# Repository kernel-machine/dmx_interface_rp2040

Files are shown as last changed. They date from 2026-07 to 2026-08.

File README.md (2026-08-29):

<div align="center">

# 🎛️ DMX USB Interface — Dual Universe

### Enttec DMX USB Pro Mk2 Emulator · Built on Raspberry Pi Pico (RP2040)






<br>

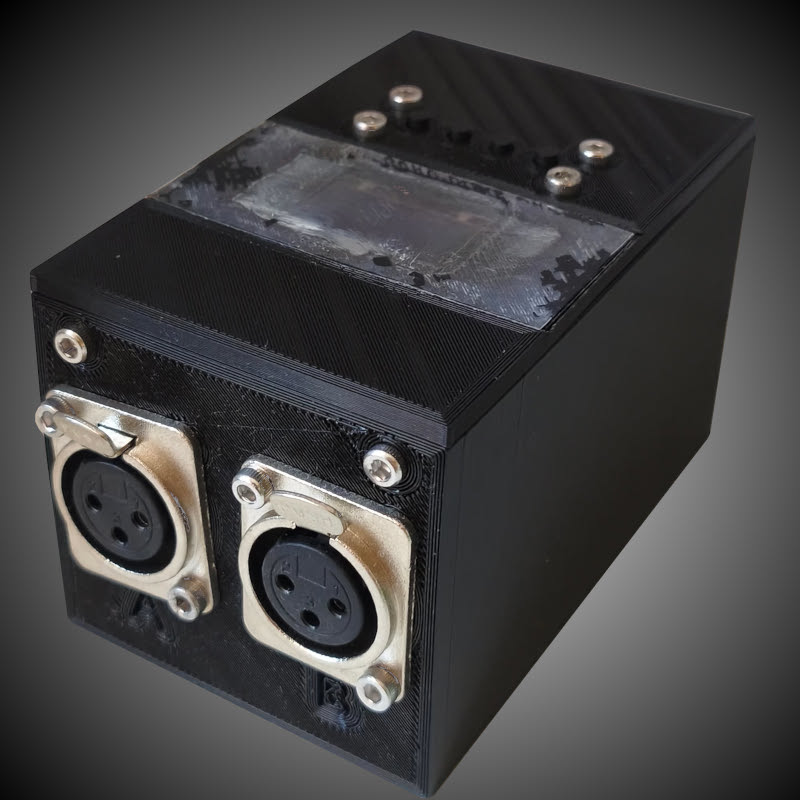
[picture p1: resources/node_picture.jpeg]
DMX USB Node


<br>

*A DIY, open-source, dual-universe DMX interface with an OLED menu, standalone CUE engine, and full galvanic isolation.*

</div>

---

## 💡 Motivation

Lighting control hardware is often expensive and hard to customize. This project provides an **affordable, reliable, and highly customizable** dual-universe DMX interface using the Raspberry Pi Pico.

By emulating the industry-standard **Enttec DMX USB Pro Mk2** protocol, the interface works **out of the box** with popular lighting software like [QLC+](https://www.qlcplus.org/) — no custom drivers required.

It also features a built-in **OLED display**, **physical controls**, and a **standalone CUE engine** for managing DMX setups directly from the device.

> **Why USB instead of ArtNet?**
> My first prototype used ArtNet, but for my use cases it was far more convenient to connect via USB rather than dealing with LAN cables, IP addresses, and DHCP configuration.

---

## 📺 Demo

Menu navigation and node introduction:

<div align="center">

Watch the demo on YouTube (https://youtu.be/CNQFU6lT2Z0)

*▶️ Click the image above to watch the video on YouTube*

</div>

---

## ✨ Features

| Feature | Description |
|---|---|
| 🔌 **Enttec Pro Mk2 Emulation** | Native compatibility with QLC+ and other major lighting software |
| 🎚️ **Dual Universe Output** | Two full DMX-512 universes via MAX485 transceivers |
| 🖥️ **OLED Menu System** | Integrated SSD1306 display + 4-button interface for on-device control |
| 💾 **Standalone CUE Engine** | Record and store up to 10 dual-universe CUEs to flash memory |
| 🔀 **DMX Crossfading** | Smooth transitions with configurable fade times |
| 🛣️ **Advanced Routing** | Flexible mapping of Universe 1/2 to physical Outputs A/B |
| 💿 **Persistent Settings** | All preferences saved to EEPROM |

### 🔌 Smart Disconnect Behavior

Configurable fallback modes when USB connection is lost:

- ⬛ **Blackout** — all channels go to zero
- ⏸️ **Hold Last Value** — freeze the last DMX frame
- 🎬 **Play CUE** — automatically trigger a stored CUE

---

## 🚀 How to Flash

This project uses **PlatformIO** with the Arduino framework for the Raspberry Pi Pico ([Earle Philhower core](https://github.com/earlephilhower/arduino-pico)).

### Option 1 — PlatformIO Upload *(Recommended)*

1. Install [Visual Studio Code](https://code.visualstudio.com/) and the [PlatformIO IDE extension](https://platformio.org/).
2. Open this project folder in VSCode.
3. Hold the **BOOTSEL** button on the Pico and plug it in via USB.
4. Once the Pico mounts as a mass storage device, click **Upload** (→) in the PlatformIO toolbar.

### Option 2 — Drag & Drop (UF2)

1. Build the project in PlatformIO (**Build** / ✓ icon).
2. Find the generated `firmware.uf2` in `.pio/build/pico/`.
3. Hold **BOOTSEL** and plug in the Pico — it appears as `RPI-RP2`.
4. Drag and drop `firmware.uf2` onto the drive. The Pico reboots automatically.

---

## 🧰 Hardware

The circuit implements **full galvanic isolation** between the USB controller and the DMX transceiver to protect the host computer from electrical faults, ground loops, and high-voltage transients.

An isolated DC-DC converter (**B0505S-1W**) supplies a dedicated floating 5 V rail, and two high-speed **6N137** optocouplers isolate the logic signals driving the MAX485.

### Bill of Materials

| # | Component | Link |
|:-:|---|---|
| 1 | **Raspberry Pi Pico (RP2040)** | [AliExpress](https://it.aliexpress.com/item/1005006087823796.html) |
| 2 | **MAX485 Transceiver Module** ×2 | [AliExpress](https://s.click.aliexpress.com/e/_c3NT3dPz) |
| 3 | **XLR 3-Pin Female Panel Connector** ×2 | [AliExpress](https://s.click.aliexpress.com/e/_c4q55Lx9) |
| 4 | **6N137 High-Speed Optocoupler** ×2 | [AliExpress](https://s.click.aliexpress.com/e/_c2JoN82B) |
| 5 | **B0505S-1W Isolated DC-DC Converter** | [AliExpress](https://s.click.aliexpress.com/e/_c4KkuvZv) |
| 6 | **Perfboard / PCB** | [AliExpress](https://it.aliexpress.com/item/1005006066751179.html) |
| 7 | **Tactile Push Buttons** ×4 | [AliExpress](https://it.aliexpress.com/item/1005005658595026.html) |
| 8 | **SSD1306 0.96″ OLED Display** | [AliExpress](https://s.click.aliexpress.com/e/_c4LZoMDz) |
| 9 | **Assorted Resistors** | — |
| 10 | **3D Printed Case** *(optional)* | See below |

---

### 📐 Wiring Diagram

> [!NOTE]
> This diagram was drawn after the build, so minor inaccuracies are possible — but it should be correct.

<div align="center">
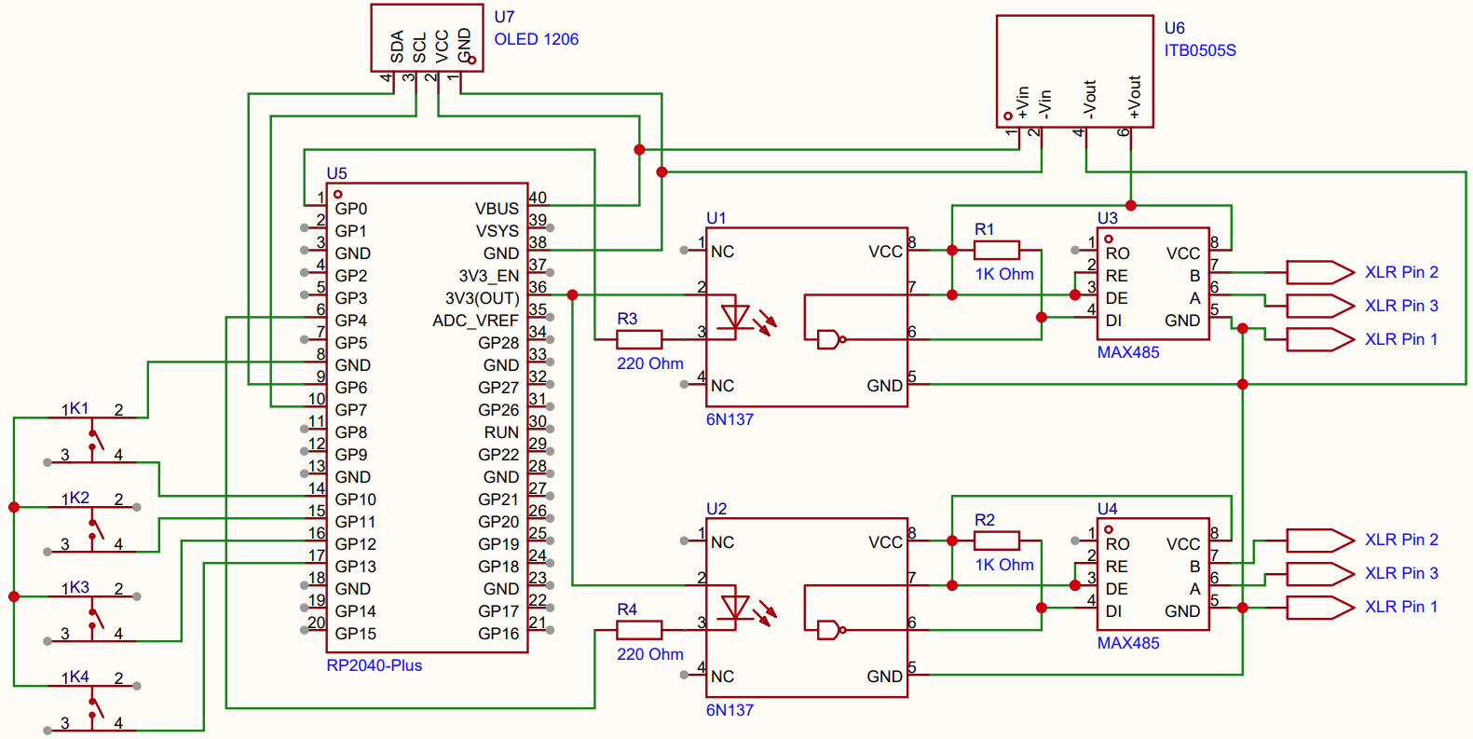
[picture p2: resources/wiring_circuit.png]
Wiring Diagram

</div>

---

### 🖨️ 3D Printed Case

The enclosure is composed of 3 parts and uses **M3 screws** for assembly:

| Part | File |
|---|---|
| Case | [`Case.stl`](./3DModels/Case.stl) |
| Top Panel | [`Top Panel.stl`](./3DModels/Top%20Panel.stl) |
| USB Panel | [`USB Panel.stl`](./3DModels/USB%20Panel.stl) |

> [!IMPORTANT]
> The USB hole position must be aligned with the RP2040 on the PCB. If you use the same perfboard and place the Pico board flush against the edge, the hole should match.

---

## 🖥️ Working with QLC+

In QLC+, select **Pro Mk2** in the mode menu:

<div align="center">
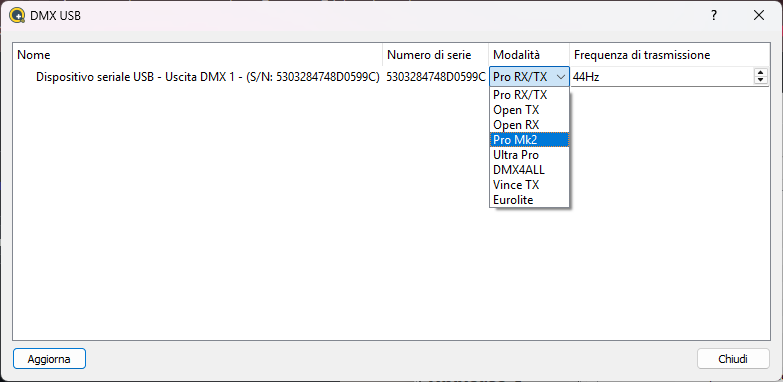
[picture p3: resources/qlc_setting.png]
QLC+ Pro Mk2 Mode Selection

</div>

---

## ⚠️ Known Issues

- The OLED screen brightness is not sufficient in direct daylight.

---

## 📷 Build Gallery

<details>
<summary><strong>Click to expand build photos</strong></summary>

<br>

#### Back of the PCB

The two opto-isolators (6N137) with their associated pull-up resistors.

<div align="center">
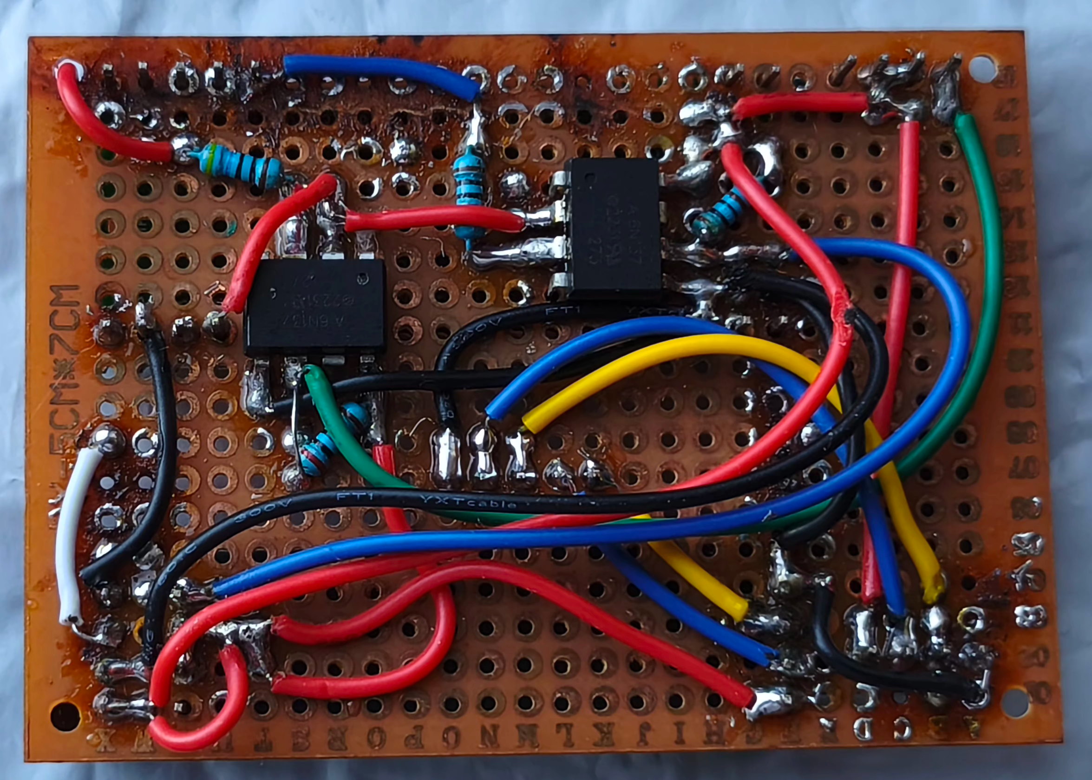
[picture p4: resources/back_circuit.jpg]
Back of the PCB — Opto-isolators

</div>

<br>

#### Board Inside the Case

The RP2040 on the right, MAX485 modules and B0505S on the bottom-left. Black connectors carry the OLED and button signals from the top panel.

<div align="center">
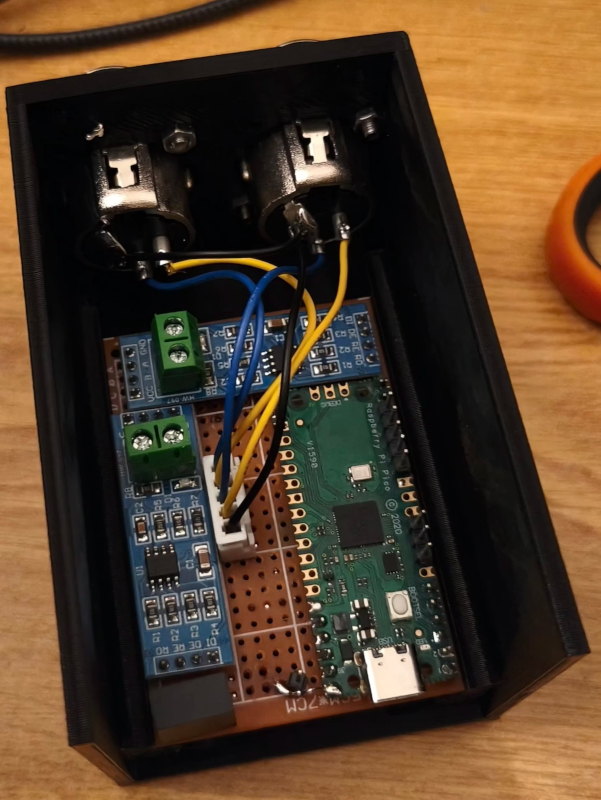
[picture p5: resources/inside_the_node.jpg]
Board inside the 3D printed case

</div>

</details>

---

## 📄 License

This project is licensed under the [Creative Commons BY-NC-SA 4.0](LICENSE.md) license.

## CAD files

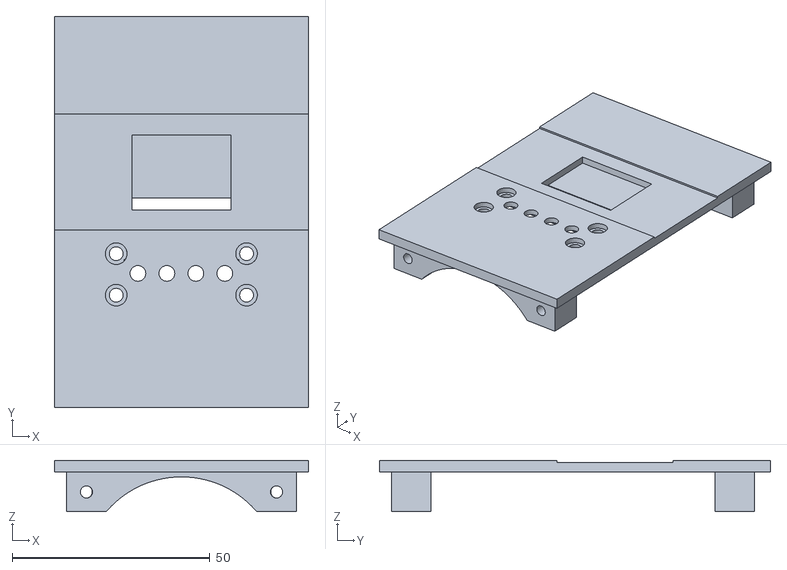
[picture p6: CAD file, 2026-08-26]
3DModels/Top Panel.stl
64.3 x 99.0 x 13.0

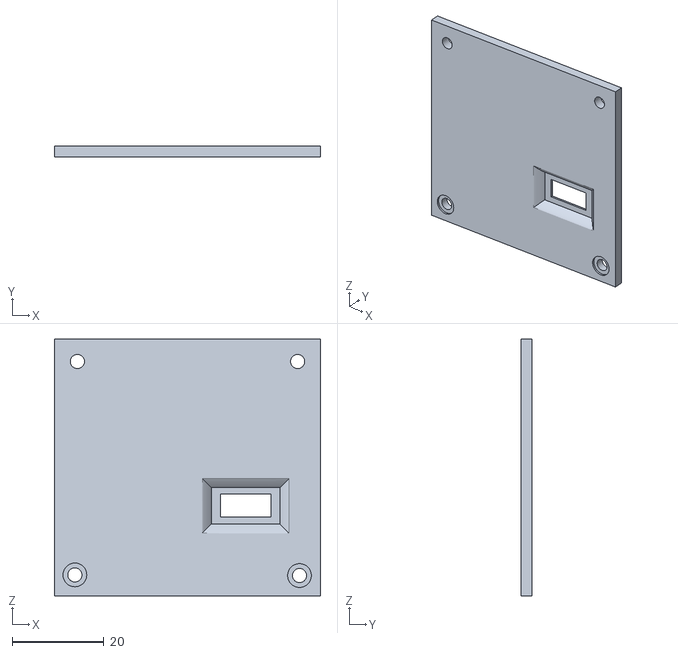
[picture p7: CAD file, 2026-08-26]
3DModels/USB Panel.stl
58.1 x 2.50 x 56.1

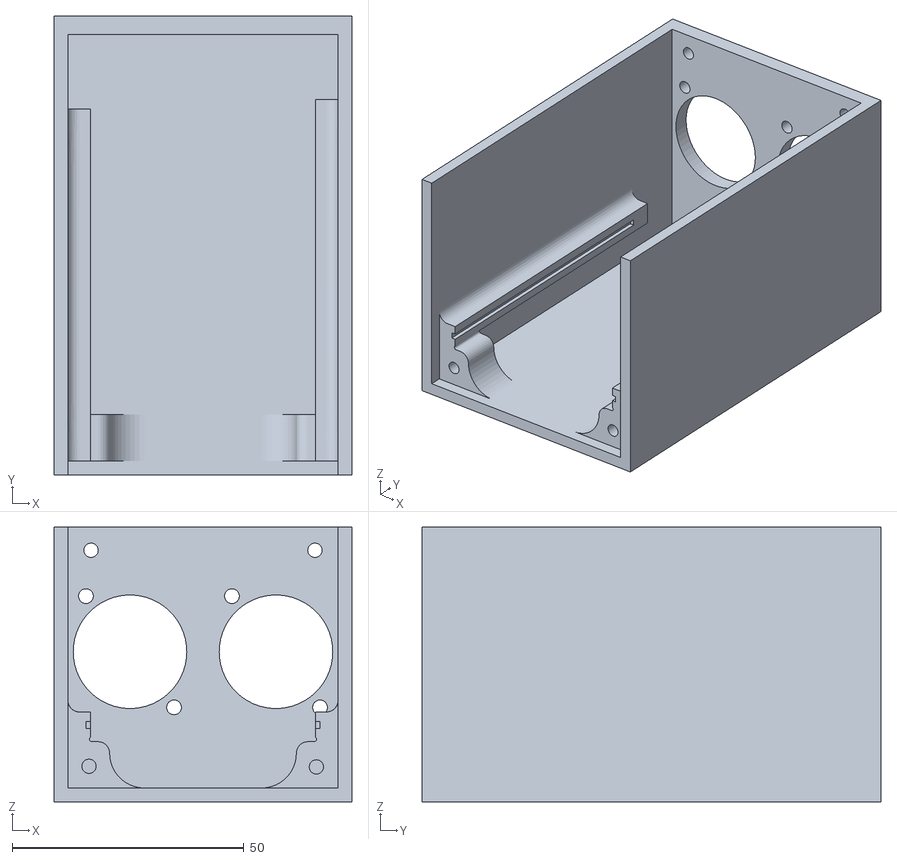
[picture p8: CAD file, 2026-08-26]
3DModels/Case.stl
64.3 x 99.0 x 59.3

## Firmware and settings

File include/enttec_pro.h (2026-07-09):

#ifndef ENTTEC_PRO_H
#define ENTTEC_PRO_H

#include <Arduino.h>

// =============================================================================
// Enttec DMX USB Pro Protocol Constants
// =============================================================================

// Frame delimiters
#define ENTTEC_START_OF_MSG  0x7E
#define ENTTEC_END_OF_MSG    0xE7

// Message Labels (PC → Widget)
#define LABEL_REPROGRAM_FW      1   // Reprogram firmware (not implemented)
#define LABEL_PROGRAM_FLASH     2   // Program flash page (not implemented)
#define LABEL_GET_PARAMS        3   // Get Widget Parameters (request/reply)
#define LABEL_SET_PARAMS        4   // Set Widget Parameters
#define LABEL_RECV_DMX          5   // Received DMX packet (widget → PC)
#define LABEL_SEND_DMX          6   // Output Only Send DMX Packet (Port 1)
#define LABEL_SEND_RDM          7   // Send RDM (not implemented)
#define LABEL_RECV_DMX_CHANGE   8   // Receive DMX on Change (not implemented)
#define LABEL_RECV_DMX_STATE    9   // Received DMX Change of State (not impl.)
#define LABEL_GET_SERIAL       10   // Get Widget Serial Number
#define LABEL_SEND_RDM_DISC    11   // Send RDM Discovery (not implemented)

// Enttec Pro Mk2 specific labels for multiple ports
#define LABEL_SEND_DMX2      0xA9   // Output Only Send DMX Packet (Port 2)
#define LABEL_PORT_ASSIGN    0xCB   // Port Assignment Request (to configure Mk2 ports)

// Extended labels (for manufacturer/device identification)
#define LABEL_GET_MANUFACTURER 77   // 0x4D - Get Device Manufacturer
#define LABEL_GET_DEVICE_NAME  78   // 0x4E - Get Device Name

// Maximum data payload size (DMX start code + 512 channels)
#define MAX_DMX_CHANNELS       512
#define MAX_ENTTEC_DATA        600

// Widget firmware version (emulated)
#define FW_VERSION_LSB         1
#define FW_VERSION_MSB         44   // v44.1 — mimics a real Pro widget

// Default widget parameters
#define DEFAULT_BREAK_TIME     9    // Break time in 10.67µs units (9 = ~96µs)
#define DEFAULT_MAB_TIME       1    // MAB time in 10.67µs units (1 = ~10.67µs)
#define DEFAULT_REFRESH_RATE   40   // DMX refresh rate in Hz (0 = max speed)

// ESTA Manufacturer ID (custom, non-registered)
#define ESTA_MANUFACTURER_ID_LSB  0x7A  // Custom ID
#define ESTA_MANUFACTURER_ID_MSB  0x70  // Custom ID

// =============================================================================
// Parser State Machine
// =============================================================================

enum EnttecParserState {
    STATE_WAIT_START,       // Waiting for 0x7E
    STATE_READ_LABEL,       // Reading message label
    STATE_READ_LEN_LSB,     // Reading data length LSB
    STATE_READ_LEN_MSB,     // Reading data length MSB
    STATE_READ_DATA,        // Reading data payload
    STATE_WAIT_END          // Waiting for 0xE7
};

// =============================================================================
// Widget Parameters (stored in RAM, not persisted)
// =============================================================================

struct WidgetParams {
    uint8_t  fwVersionLSB;
    uint8_t  fwVersionMSB;
    uint8_t  breakTime;     // In 10.67µs units
    uint8_t  mabTime;       // In 10.67µs units
    uint8_t  refreshRate;   // In Hz (0 = fastest)
};

// =============================================================================
// Enttec Pro Protocol Handler Class
// =============================================================================

class EnttecPro {
public:
    EnttecPro();

    /// Initialize the protocol handler
    void begin();

    /// Process a single byte received from USB Serial.
    /// Call this for each byte read from Serial.
    void processByte(uint8_t byte);

    /// Check if new DMX data is available for a given universe (0 or 1)
    bool hasDmxData(uint8_t universe) const;

    /// Get pointer to the 512-byte DMX channel buffer for a given universe (0 or 1)
    const uint8_t* getDmxData(uint8_t universe) const;

    /// Get the number of DMX channels in the last received packet for a universe (0 or 1)
    uint16_t getDmxLength(uint8_t universe) const;

    /// Clear the new-data flag for a universe (0 or 1)
    void clearDmxFlag(uint8_t universe);

private:
    // Parser state
    EnttecParserState m_state;
    uint8_t  m_label;
    uint16_t m_dataLength;
    uint16_t m_dataIndex;
    uint8_t  m_dataBuffer[MAX_ENTTEC_DATA];

    // Widget parameters
    WidgetParams m_params;

    // DMX output buffers (universe 0 = Port 1, universe 1 = Port 2)
    uint8_t  m_dmxBuffer[2][MAX_DMX_CHANNELS];
    uint16_t m_dmxLength[2];
    bool     m_newDmxData[2];

    // Widget serial number (fixed)
    uint8_t  m_serialNumber[4];

    // Send a reply message back to the PC via USB Serial
    void sendReply(uint8_t label, const uint8_t* data, uint16_t length);

    // Message handlers
    void handleGetParams();
    void handleSetParams();
    void handleSendDmx(uint8_t universe);
    void handlePortAssign();
    void handleGetSerial();
    void handleGetManufacturer();
    void handleGetDeviceName();
    void handleMessage();
};

#endif // ENTTEC_PRO_H

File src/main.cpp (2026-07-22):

// =============================================================================
// Pico DMX Interface — Enttec DMX USB Pro Emulator (Dual Universe)
// =============================================================================
//
// This firmware makes a Raspberry Pi Pico act as an Enttec DMX USB Pro Mk2
// compatible interface for QLC+ and other lighting control software.
//
// Hardware:
//   - GP0 (Output 1 / Universe 1) → MAX485 (1) DI
//   - GP1                         → MAX485 (1) DE + RE̅ (tied together, HIGH =
//   TX)
//   - GP4 (Output 2 / Universe 2) → MAX485 (2) DI
//   - GP5                         → MAX485 (2) DE + RE̅ (tied together, HIGH =
//   TX)
//   - USB                         → PC running QLC+
//
// Protocol:
//   USB Serial (CDC) ←→ Enttec Pro Mk2 protocol ←→ DMX512 via PIO (Pico-DMX)
//
// =============================================================================

// SSD1206
// GND (Green) -> GND
// SDA (Yellow) -> GP6
// SCL (Orange) -> GP7
// VCC (Brown) -> 5V

// Buttons
// K1 (White) -> GP10
// K2 (Gray) -> GP11
// K3 (Purple) -> GP12
// K4 (Blue) -> GP13
// GND (Green) -> GND

#include "dmx_driver.h"
#include "enttec_pro.h"
#include <Adafruit_SSD1306.h>
#include <Arduino.h>
#include <EEPROM.h>
#include <Wire.h>
#include <hardware/flash.h>
#include <hardware/sync.h>

#define BUTTON_K1 10
#define BUTTON_K2 11
#define BUTTON_K3 12
#define BUTTON_K4 13

static const int buttonPins[4] = {BUTTON_K1, BUTTON_K2, BUTTON_K3, BUTTON_K4};
static const char *buttonNames[4] = {"M", "^", "v", "Ent"};
static String lastPressedKey = "None";

#define SDA_PIN 6
#define SCL_PIN 7
#define SCREEN_WIDTH 128 // OLED display width, in pixels
#define SCREEN_HEIGHT 64 // OLED display height, in pixels
#define OLED_RESET -1    // Reset pin # (or -1 if sharing Arduino reset pin)
#define SCREEN_ADDRESS                                                         \
  0x3C ///< See datasheet for Address; 0x3D for 128x64, 0x3C for 128x32

Adafruit_SSD1306 display(SCREEN_WIDTH, SCREEN_HEIGHT, &Wire1, OLED_RESET);

// LED pin for status indication
#define LED_PIN LED_BUILTIN

// Menu States
enum MenuState {
  STATE_NORMAL,
  STATE_MENU_MAIN,
  STATE_SET_REFRESH_RATE,
  STATE_SET_DISCONNECT_MODE,
  STATE_SET_ROUTING,
  STATE_SET_SCREENSAVER_TIMEOUT,
  STATE_SET_FADE_TIME,
  STATE_MENU_CUES,       // Select CUE index (1 to 10)
  STATE_MENU_CUE_ACTION, // Select Play / Record / Back
  STATE_PLAYING_CUE,     // Playback mode screen
  STATE_CUE_FEEDBACK     // Action feedback screen (brief auto-dismiss message)
};

// Feedback Types
enum FeedbackType { FEEDBACK_RECORDED, FEEDBACK_DELETED };

// Disconnect Modes
enum DisconnectMode { MODE_BLACKOUT = 0, MODE_HOLD_LAST = 1 };

// Menu Items
enum MenuItem {
  ITEM_REFRESH_RATE,
  ITEM_DISCONNECT_MODE,
  ITEM_ROUTING,
  ITEM_SCREENSAVER_TIMEOUT,
  ITEM_FADE_TIME,
  ITEM_CUES,
  ITEM_EXIT,
  ITEM_COUNT // Helper
};

static const char *menuItemNames[ITEM_COUNT] = {
    "DMX Refresh Rate", "On Disconnect", "DMX Routing", "Screensaver Time",
    "Fade Time",        "CUEs",          "Exit"};

// CUE Storage Constants
#define CUE_SIZE 1024 // 512 bytes Universe 1 + 512 bytes Universe 2
#define NUM_CUES 10
#define FLASH_CUES_OFFSET                                                      \
  0x80000 // 512 KB offset from start of flash (safe from sketch & filesystem
          // sectors)
#define FLASH_CUES_ADDR (XIP_BASE + FLASH_CUES_OFFSET)
#define EEPROM_CUE_RECORDED_START_ADDR 10

// State Variables
static MenuState currentMenuState = STATE_NORMAL;
static int mainMenuCursor = 0;
static uint8_t dmxFpsSetting = 40;  // Default DMX refresh rate
static uint8_t tempFpsSetting = 40; // Temporary value for setting edit
static uint8_t disconnectModeSetting =
    MODE_BLACKOUT; // Default disconnect behavior
static uint8_t tempDisconnectMode =
    MODE_BLACKOUT; // Temporary value for disconnect edit
static bool universeTimedOut[2] = {false,
                                   false}; // Track universe timeout state

static bool cueRecorded[NUM_CUES] = {false}; // Track if each CUE is saved
static int cueMenuCursor = 0; // Selector cursor for CUE list menu
static int cueActionCursor =
    0; // Selector cursor for CUE action menu (Play/Record/Back)
static int selectedCue = 0; // Currently selected CUE index (0..9)
static int playingCue = -1; // Currently playing CUE index (0..9), or -1 if live
static FeedbackType activeFeedback =
    FEEDBACK_RECORDED;                      // Current feedback to display
static unsigned long feedbackStartTime = 0; // Millis when feedback view started
static unsigned long lastUserInteractionTime =
    0; // Tracks last user interaction (button press)
static bool screenSaverActive = false; // Tracks if OLED screensaver is active

static uint8_t screensaverTimeoutSetting =
    60; // Screensaver timeout in seconds (0 = disabled)
static uint8_t tempScreensaverTimeout = 60; // Temporary value for setting edit
static uint8_t fadeTimeSetting = 3; // Fade time in seconds for CUE transitions
static uint8_t tempFadeTime = 3;    // Temporary value for fade time edit

// DMX state tracker and crossfade engine
static uint8_t currentDmxValues[2][512] = {{0}, {0}};
static bool isCrossFading = false;
static unsigned long crossFadeStartTime = 0;
static unsigned long crossFadeDuration = 0;
static uint8_t crossFadeStartBuffer[2][512] = {{0}, {0}};
static uint8_t crossFadeTargetBuffer[2][512] = {{0}, {0}};

#define ROUTE_NONE 0
#define ROUTE_OUT_A 1
#define ROUTE_OUT_B 2
#define ROUTE_BOTH 3

enum RoutingMode {
  ROUTE_MODE_1 = 0, // 1->A, 2->B
  ROUTE_MODE_2 = 1, // 1->B, 2->A
  ROUTE_MODE_3 = 2, // 1->A, 1->B
  ROUTE_MODE_4 = 3  // 2->A, 2->B
};

static uint8_t routingModeSetting = ROUTE_MODE_1;
static uint8_t tempRoutingMode = ROUTE_MODE_1;

#define EEPROM_MAGIC 0x5A
#define EEPROM_MAGIC_ADDR 0
#define EEPROM_FPS_ADDR 1
#define EEPROM_DISCONNECT_MODE_ADDR 2
#define EEPROM_SCREENSAVER_TIMEOUT_ADDR 3
#define EEPROM_FADE_TIME_ADDR 4
#define EEPROM_ROUTING_MODE_ADDR 5

// EEPROM settings management
void loadSettings() {
  EEPROM.begin(256);
  uint8_t magic = EEPROM.read(EEPROM_MAGIC_ADDR);
  if (magic == EEPROM_MAGIC) {
    dmxFpsSetting = EEPROM.read(EEPROM_FPS_ADDR);
    if (dmxFpsSetting > 44) {
      dmxFpsSetting = 44;
    }
    disconnectModeSetting = EEPROM.read(EEPROM_DISCONNECT_MODE_ADDR);
    screensaverTimeoutSetting = EEPROM.read(EEPROM_SCREENSAVER_TIMEOUT_ADDR);
    if (screensaverTimeoutSetting > 240) {
      screensaverTimeoutSetting = 60; // Default if invalid
    }
    fadeTimeSetting = EEPROM.read(EEPROM_FADE_TIME_ADDR);
    if (fadeTimeSetting > 10) {
      fadeTimeSetting = 3; // Default if invalid (3 seconds)
    }
    routingModeSetting = EEPROM.read(EEPROM_ROUTING_MODE_ADDR);
    if (routingModeSetting > 3) {
      routingModeSetting = ROUTE_MODE_1;
    }
    for (int i = 0; i < NUM_CUES; i++) {
      cueRecorded[i] = (EEPROM.read(EEPROM_CUE_RECORDED_START_ADDR + i) == 1);
    }
    if (disconnectModeSetting > 11) {
      disconnectModeSetting = MODE_BLACKOUT; // Sanity check
    } else if (disconnectModeSetting >= 2) {
      int cueIdx = disconnectModeSetting - 2;
      if (!cueRecorded[cueIdx]) {
        disconnectModeSetting = MODE_BLACKOUT; // Fallback if CUE is empty
      }
    }
  } else {
    // Not initialized, save default values
    dmxFpsSetting = 40;
    disconnectModeSetting = MODE_BLACKOUT;
    screensaverTimeoutSetting = 60;
    fadeTimeSetting = 3;
    routingModeSetting = ROUTE_MODE_1;
    EEPROM.write(EEPROM_MAGIC_ADDR, EEPROM_MAGIC);
    EEPROM.write(EEPROM_FPS_ADDR, dmxFpsSetting);
    EEPROM.write(EEPROM_DISCONNECT_MODE_ADDR, disconnectModeSetting);
    EEPROM.write(EEPROM_SCREENSAVER_TIMEOUT_ADDR, screensaverTimeoutSetting);
    EEPROM.write(EEPROM_FADE_TIME_ADDR, fadeTimeSetting);
    EEPROM.write(EEPROM_ROUTING_MODE_ADDR, routingModeSetting);
    for (int i = 0; i < NUM_CUES; i++) {
      cueRecorded[i] = false;
      EEPROM.write(EEPROM_CUE_RECORDED_START_ADDR + i, 0);
    }
    EEPROM.commit();
  }
}

void saveSettings() {
  EEPROM.write(EEPROM_MAGIC_ADDR, EEPROM_MAGIC);
  EEPROM.write(EEPROM_FPS_ADDR, dmxFpsSetting);
  EEPROM.write(EEPROM_DISCONNECT_MODE_ADDR, disconnectModeSetting);
  EEPROM.write(EEPROM_SCREENSAVER_TIMEOUT_ADDR, screensaverTimeoutSetting);
  EEPROM.write(EEPROM_FADE_TIME_ADDR, fadeTimeSetting);
  EEPROM.write(EEPROM_ROUTING_MODE_ADDR, routingModeSetting);
  for (int i = 0; i < NUM_CUES; i++) {
    EEPROM.write(EEPROM_CUE_RECORDED_START_ADDR + i, cueRecorded[i] ? 1 : 0);
  }
  EEPROM.commit();
}

uint8_t getMappedInputForOutput(uint8_t outPort) {
  if (outPort == 0) { // Output A
    return (routingModeSetting == ROUTE_MODE_1 ||
            routingModeSetting == ROUTE_MODE_3)
               ? 0
               : 1;
  } else { // Output B
    return (routingModeSetting == ROUTE_MODE_2 ||
            routingModeSetting == ROUTE_MODE_3)
               ? 0
               : 1;
  }
}

// Returns true if the specified input (1 or 2) has at least one assigned output port
bool hasRoute(uint8_t input) {
  uint8_t inPort = (input == 2) ? 1 : 0;
  return (getMappedInputForOutput(0) == inPort ||
          getMappedInputForOutput(1) == inPort);
}

const uint8_t *getLiveDmxDataForOutput(uint8_t outPort) {
  extern EnttecPro enttecPro;
  uint8_t inPort = getMappedInputForOutput(outPort);
  return enttecPro.getDmxData(inPort);
}


const uint8_t *getTimeoutDataForOutput(uint8_t outPort) {
  if (disconnectModeSetting == MODE_BLACKOUT) {
    static const uint8_t zeroData[512] = {0};
    return zeroData;
  } else if (disconnectModeSetting == MODE_HOLD_LAST) {
    return nullptr;
  } else if (disconnectModeSetting >= 2 && disconnectModeSetting <= 11) {
    int cueIdx = disconnectModeSetting - 2;
    const uint8_t *flash_cues_ptr = (const uint8_t *)FLASH_CUES_ADDR;
    return flash_cues_ptr + (cueIdx * CUE_SIZE) + (outPort * 512);
  }
  return nullptr;
}

void recordCue(int cueIdx) {
  if (cueIdx < 0 || cueIdx >= NUM_CUES)
    return;

  // Allocate a temporary buffer for all 10 CUEs in RAM
  uint8_t *tempBuffer = (uint8_t *)malloc(NUM_CUES * CUE_SIZE);
  if (!tempBuffer)
    return;

  // Copy current flash CUE contents into RAM buffer
  const uint8_t *flash_cues_ptr = (const uint8_t *)FLASH_CUES_ADDR;
  memcpy(tempBuffer, flash_cues_ptr, NUM_CUES * CUE_SIZE);

  // Update the target CUE space with current live DMX values
  uint8_t *targetCue = tempBuffer + (cueIdx * CUE_SIZE);
  memcpy(targetCue, currentDmxValues[0], 512);
  memcpy(targetCue + 512, currentDmxValues[1], 512);

  // Disable interrupts and reprogram flash
  uint32_t ints = save_and_disable_interrupts();

  // Erase 3 sectors (12 KB) at offset FLASH_CUES_OFFSET
  flash_range_erase(FLASH_CUES_OFFSET, 3 * FLASH_SECTOR_SIZE);

  // Program 10,240 bytes at offset FLASH_CUES_OFFSET
  flash_range_program(FLASH_CUES_OFFSET, tempBuffer, NUM_CUES * CUE_SIZE);

  restore_interrupts(ints);

  free(tempBuffer);

  // Update EEPROM flag for this CUE
  cueRecorded[cueIdx] = true;
  saveSettings();
}

// Global instances
EnttecPro enttecPro;
DmxDriver dmxOutput;

// Activity LED state
static unsigned long lastActivityTime = 0;
static bool ledState = false;

// OLED update timing and statistics
static unsigned long lastOledUpdate = 0;
static unsigned long lastDmxTime[2] = {0, 0};
static uint32_t dmxPacketCount[2] = {0, 0};
static unsigned long u1LedOnUntil = 0;
static unsigned long u2LedOnUntil = 0;
static bool hasDisplay = false;

// =============================================================================
// Setup
// =============================================================================
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
void loop() {
  // --------------------------------------------------
  // 0. Read and debounce buttons
  // --------------------------------------------------
  static bool btnState[4] = {HIGH, HIGH, HIGH, HIGH};
  static unsigned long btnLastDebounce[4] = {0, 0, 0, 0};

  bool k1Pressed = false;
  bool k2Pressed = false;
  bool k3Pressed = false;
  bool k4Pressed = false;

  for (int i = 0; i < 4; i++) {
    bool currentVal = digitalRead(buttonPins[i]);
    if (currentVal != btnState[i]) {
      if (millis() - btnLastDebounce[i] > 50) {
        btnState[i] = currentVal;
        btnLastDebounce[i] = millis();
        if (currentVal == LOW) { // Pressed!
          lastPressedKey = buttonNames[i];
          if (i == 0)
            k1Pressed = true;
          else if (i == 1)
            k2Pressed = true;
          else if (i == 2)
            k3Pressed = true;
          else if (i == 3)
            k4Pressed = true;

          // Force immediate update of display for snappy feedback
          lastOledUpdate = 0;
        }
      }
    }
  }

  // Intercept button presses to manage screensaver and exit hold last mode if
  // timed out
  if (k1Pressed || k2Pressed || k3Pressed || k4Pressed) {
    lastUserInteractionTime = millis();

    // Exit hold last mode on manual button press
    for (int port = 0; port < 2; port++) {
      if (universeTimedOut[port] &&
          (disconnectModeSetting == MODE_HOLD_LAST ||
           (disconnectModeSetting >= 2 && disconnectModeSetting <= 11))) {
        universeTimedOut[port] = false;
        lastDmxTime[port] = millis(); // Prevent immediate re-timeout
        bool routesToA = (getMappedInputForOutput(0) == port);
        bool routesToB = (getMappedInputForOutput(1) == port);
        const uint8_t *targetA =
            routesToA ? getLiveDmxDataForOutput(0) : nullptr;
        const uint8_t *targetB =
            routesToB ? getLiveDmxDataForOutput(1) : nullptr;
        if (targetA || targetB) {
          startCrossFade(targetA, targetB,
                         (unsigned long)fadeTimeSetting * 1000);
        }
      }
    }

    if (screenSaverActive) {
      screenSaverActive = false;
      display.ssd1306_command(SSD1306_DISPLAYON);
      display.ssd1306_command(SSD1306_SETCONTRAST);
      display.ssd1306_command(0xFF); // Ensure maximum brightness on wake
      // Force redraw immediately
      lastOledUpdate = 0;
      // Consume the presses to prevent triggering actions on wake up
      k1Pressed = false;
      k2Pressed = false;
      k3Pressed = false;
      k4Pressed = false;
    }
  }

  // Check if screensaver should turn on (based on screensaverTimeoutSetting in
  // seconds, 0 = disabled)
  if (screensaverTimeoutSetting > 0 && !screenSaverActive &&
      (millis() - lastUserInteractionTime >=
       (unsigned long)screensaverTimeoutSetting * 1000)) {
    screenSaverActive = true;
    display.ssd1306_command(SSD1306_DISPLAYOFF);
  }

  // --------------------------------------------------
  // Menu State Machine Logic
  // --------------------------------------------------
  if (currentMenuState == STATE_NORMAL) {
    if (k1Pressed) {
      currentMenuState = STATE_MENU_MAIN;
      mainMenuCursor = 0;
      lastOledUpdate = 0;
    }
  } else if (currentMenuState == STATE_MENU_MAIN) {
    if (k1Pressed) { // Back
      currentMenuState = STATE_NORMAL;
      lastOledUpdate = 0;
    } else if (k2Pressed) { // Scroll Up
      mainMenuCursor = (mainMenuCursor - 1 + ITEM_COUNT) % ITEM_COUNT;
      lastOledUpdate = 0;
    } else if (k3Pressed) { // Scroll Down
      mainMenuCursor = (mainMenuCursor + 1) % ITEM_COUNT;
      lastOledUpdate = 0;
    } else if (k4Pressed) { // Enter
      if (mainMenuCursor == ITEM_REFRESH_RATE) {
        currentMenuState = STATE_SET_REFRESH_RATE;
        tempFpsSetting = dmxFpsSetting;
      } else if (mainMenuCursor == ITEM_DISCONNECT_MODE) {
        currentMenuState = STATE_SET_DISCONNECT_MODE;
        tempDisconnectMode = disconnectModeSetting;
      } else if (mainMenuCursor == ITEM_ROUTING) {
        currentMenuState = STATE_SET_ROUTING;
        tempRoutingMode = routingModeSetting;
      } else if (mainMenuCursor == ITEM_SCREENSAVER_TIMEOUT) {
        currentMenuState = STATE_SET_SCREENSAVER_TIMEOUT;
        tempScreensaverTimeout = screensaverTimeoutSetting;
      } else if (mainMenuCursor == ITEM_FADE_TIME) {
        currentMenuState = STATE_SET_FADE_TIME;
        tempFadeTime = fadeTimeSetting;
      } else if (mainMenuCursor == ITEM_CUES) {
        currentMenuState = STATE_MENU_CUES;
        cueMenuCursor = 0;
      } else if (mainMenuCursor == ITEM_EXIT) {
        currentMenuState = STATE_NORMAL;
      }
      lastOledUpdate = 0;
    }
  } else if (currentMenuState == STATE_SET_REFRESH_RATE) {
    if (k1Pressed) { // Cancel
      currentMenuState = STATE_MENU_MAIN;
      lastOledUpdate = 0;
    } else if (k2Pressed) { // Increase
      if (tempFpsSetting == 0) {
        tempFpsSetting = 10;
      } else if (tempFpsSetting < 44) {
        tempFpsSetting++;
      }
      lastOledUpdate = 0;
    } else if (k3Pressed) { // Decrease
      if (tempFpsSetting == 10) {
        tempFpsSetting = 0; // Max
      } else if (tempFpsSetting > 10) {
        tempFpsSetting--;
      }
      lastOledUpdate = 0;
    } else if (k4Pressed) { // Save
      dmxFpsSetting = tempFpsSetting;
      saveSettings();
      dmxOutput.setRefreshRate(dmxFpsSetting);
      currentMenuState = STATE_MENU_MAIN;
      lastOledUpdate = 0;
    }
  } else if (currentMenuState == STATE_SET_DISCONNECT_MODE) {
    if (k1Pressed) { // Cancel
      currentMenuState = STATE_MENU_MAIN;
      lastOledUpdate = 0;
    } else if (k2Pressed) { // Scroll forward/next option
      uint8_t nextMode = tempDisconnectMode;
      while (true) {
        nextMode = (nextMode + 1) % 12; // 0..11
        if (nextMode == MODE_BLACKOUT || nextMode == MODE_HOLD_LAST) {
          break;
        }
        int cueIdx = nextMode - 2;
        if (cueRecorded[cueIdx]) {
          break;
        }
      }
      tempDisconnectMode = nextMode;
      lastOledUpdate = 0;
    } else if (k3Pressed) { // Scroll backward/prev option
      uint8_t prevMode = tempDisconnectMode;
      while (true) {
        prevMode = (prevMode - 1 + 12) % 12;
        if (prevMode == MODE_BLACKOUT || prevMode == MODE_HOLD_LAST) {
          break;
        }
        int cueIdx = prevMode - 2;
        if (cueRecorded[cueIdx]) {
          break;
        }
      }
      tempDisconnectMode = prevMode;
      lastOledUpdate = 0;
    } else if (k4Pressed) { // Save
      disconnectModeSetting = tempDisconnectMode;
      saveSettings();
      // Apply blackout or play CUE immediately if we are currently timed out
      for (int port = 0; port < 2; port++) {
        if (universeTimedOut[port]) {
          if (disconnectModeSetting == MODE_BLACKOUT) {
            uint8_t zeroData[DMX_CHANNELS_MAX] = {0};
            dmxOutput.setData(port, zeroData, DMX_CHANNELS_MAX);
          } else if (disconnectModeSetting >= 2 &&
                     disconnectModeSetting <= 11) {
            int cueIdx = disconnectModeSetting - 2;
            const uint8_t *flash_cues_ptr = (const uint8_t *)FLASH_CUES_ADDR;
            const uint8_t *cue_ptr =
                flash_cues_ptr + (cueIdx * CUE_SIZE) + (port * 512);
            dmxOutput.setData(port, cue_ptr, 512);
          }
        }
      }
      currentMenuState = STATE_MENU_MAIN;
      lastOledUpdate = 0;
    }
  } else if (currentMenuState == STATE_SET_ROUTING) {
    if (k1Pressed) { // Cancel
      currentMenuState = STATE_MENU_MAIN;
      lastOledUpdate = 0;
    } else if (k2Pressed) { // Next Option
      tempRoutingMode = (tempRoutingMode + 1) % 4;
      lastOledUpdate = 0;
    } else if (k3Pressed) { // Prev Option
      tempRoutingMode = (tempRoutingMode - 1 + 4) % 4;
      lastOledUpdate = 0;
    } else if (k4Pressed) { // Save
      routingModeSetting = tempRoutingMode;
      saveSettings();
      // Clear timeout for inputs that are no longer routed
      for (int port = 0; port < 2; port++) {
        if (!hasRoute(port + 1)) {
          universeTimedOut[port] = false;
        }
      }
      currentMenuState = STATE_MENU_MAIN;
      lastOledUpdate = 0;
    }
  } else if (currentMenuState == STATE_SET_SCREENSAVER_TIMEOUT) {
    if (k1Pressed) { // Cancel
      currentMenuState = STATE_MENU_MAIN;
      lastOledUpdate = 0;
    } else if (k2Pressed) { // Increase (Max 240s)
      if (tempScreensaverTimeout < 240) {
        tempScreensaverTimeout += 10;
      }
      lastOledUpdate = 0;
    } else if (k3Pressed) { // Decrease (Min 0)
      if (tempScreensaverTimeout >= 10) {
        tempScreensaverTimeout -= 10;
      }
      lastOledUpdate = 0;
    } else if (k4Pressed) { // Save
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

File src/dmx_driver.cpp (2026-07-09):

#include "dmx_driver.h"

// =============================================================================
// Constructor
// =============================================================================

DmxDriver::DmxDriver()
    : m_refreshRate(DMX_DEFAULT_FPS)
    , m_lastFrameTime(0)
    , m_frameInterval(25000)  // 40 FPS default = 25000µs
{
    // Instantiate PicoDMX engines
    m_dmxEngine[0] = new ::DmxOutput();
    m_dmxEngine[1] = new ::DmxOutput();

    // Initialize buffers (index 0 is the start code, standard is 0)
    memset(m_buffer[0], 0, DMX_CHANNELS_MAX + 1);
    memset(m_buffer[1], 0, DMX_CHANNELS_MAX + 1);

    m_length[0] = DMX_CHANNELS_MAX;
    m_length[1] = DMX_CHANNELS_MAX;
}

DmxDriver::~DmxDriver() {
    delete m_dmxEngine[0];
    delete m_dmxEngine[1];
}

// =============================================================================
// Initialize PIO blocks and GPIOs
// =============================================================================

void DmxDriver::begin() {
    // Pin DE setup for both RS485 transceivers (keep HIGH to enable TX)
    pinMode(DMX1_DE_PIN, OUTPUT);
    digitalWrite(DMX1_DE_PIN, HIGH);

    pinMode(DMX2_DE_PIN, OUTPUT);
    digitalWrite(DMX2_DE_PIN, HIGH);

    // Initialize PicoDMX Port 1 on pio0
    m_dmxEngine[0]->begin(DMX1_TX_PIN, pio0);

    // Initialize PicoDMX Port 2 on pio1 (using pio1 to avoid state machine conflicts)
    m_dmxEngine[1]->begin(DMX2_TX_PIN, pio1);

    setRefreshRate(m_refreshRate);
}

// =============================================================================
// Set DMX channel data for a given port
// =============================================================================

void DmxDriver::setData(uint8_t port, const uint8_t* data, uint16_t length) {
    if (port > 1) return;
    if (length > DMX_CHANNELS_MAX) {
        length = DMX_CHANNELS_MAX;
    }
    
    // Copy data starting from index 1. Index 0 remains 0 (Start Code)
    memcpy(&m_buffer[port][1], data, length);
    m_length[port] = length;
}

// =============================================================================
// Set refresh rate
// =============================================================================

void DmxDriver::setRefreshRate(uint8_t fps) {
    m_refreshRate = fps;
    if (fps == 0) {
        m_frameInterval = 0;
    } else {
        m_frameInterval = 1000000UL / fps;
    }
}

// =============================================================================
// Send a complete DMX frame on a given port
// =============================================================================

void DmxDriver::sendFrame(uint8_t port) {
    if (port > 1) return;

    // Send packet using PicoDMX PIO engine (non-blocking call)
    // We send m_length[port] + 1 (data channels + 1 start code byte)
    m_dmxEngine[port]->write(m_buffer[port], m_length[port] + 1);
}

// =============================================================================
// Periodic update — call from loop()
// =============================================================================

void DmxDriver::update() {
    unsigned long now = micros();

    if (m_frameInterval == 0 || (now - m_lastFrameTime) >= m_frameInterval) {
        // Transmit frames on both outputs
        sendFrame(0);
        sendFrame(1);
        m_lastFrameTime = now;
    }
}

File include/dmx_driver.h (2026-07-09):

#ifndef DMX_DRIVER_H
#define DMX_DRIVER_H

#include <Arduino.h>
// Include directly from the Pico-DMX library
#include <DmxOutput.h> 

// Port 1 Pin definitions (pio0)
#define DMX1_TX_PIN      0   // GP0 — Output pin for Port 1
#define DMX1_DE_PIN      1   // GP1 — Direction Enable pin for Port 1

// Port 2 Pin definitions (pio1)
#define DMX2_TX_PIN      4   // GP4 — Output pin for Port 2
#define DMX2_DE_PIN      5   // GP5 — Direction Enable pin for Port 2

// DMX512 timing constants
#define DMX_CHANNELS_MAX    512     // Maximum DMX channels
#define DMX_DEFAULT_FPS     40      // Default refresh rate (frames per second)

// =============================================================================
// DMX Driver Class (wrapper around PicoDMX)
// =============================================================================

class DmxDriver {
public:
    DmxDriver();
    ~DmxDriver();

    /// Initialize PIO blocks and GPIOs for both DMX outputs
    void begin();

    /// Set the DMX channel data to transmit for a given port (0 or 1).
    /// @param port    Port index (0 = Port 1, 1 = Port 2)
    /// @param data    Pointer to channel data (channel 1 at index 0)
    /// @param length  Number of channels (1–512)
    void setData(uint8_t port, const uint8_t* data, uint16_t length);

    /// Transmit one complete DMX frame on a given port (0 or 1).
    void sendFrame(uint8_t port);

    /// Set the refresh rate (frames per second, 0 = max speed)
    void setRefreshRate(uint8_t fps);

    /// Check if it's time to send the next frames based on refresh rate.
    /// If so, sends the frames automatically.
    void update();

private:
    // Pointers to the Pico-DMX DmxOutput engines
    ::DmxOutput* m_dmxEngine[2];

    // Buffer to hold DMX data.
    // The PicoDMX library requires 513 bytes (Index 0 = Start Code = 0)
    uint8_t  m_buffer[2][DMX_CHANNELS_MAX + 1];

    uint16_t m_length[2];                     // Number of active channels per port
    uint8_t  m_refreshRate;                  // Target FPS
    unsigned long m_lastFrameTime;           // micros() of last frame
    unsigned long m_frameInterval;           // Interval between frames in µs
};

#endif // DMX_DRIVER_H

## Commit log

2026-07-22 Fixed timeout un unassigned ports
    [enttec_pro.cpp, main.cpp]
2026-08-26 added 3d models
    [Case.stl, Top Panel.stl, USB Panel.stl]
2026-08-26 Refactor README for clarity and alignment details
    Removed duplicate project description and added details about USB hole alignment.
2026-11-01 added capacitors

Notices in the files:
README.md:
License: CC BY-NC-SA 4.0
